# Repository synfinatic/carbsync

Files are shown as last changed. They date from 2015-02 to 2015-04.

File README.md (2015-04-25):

### CarbSync

While there are some good tools already on the market by companies like
[MotionPro](http://www.motionpro.com/motorcycle/partno/08-0411/) or 
[Morgan Carbtune](http://www.carbtune.com/), they tend to be complicated,
may use fluids which are toxic or spill, and require a complex calibration
sequence for best results.

CarbSync is a simple tool for syncing carberators or throttle bodies which uses
digital vacuum gauges to measure the vacuum on 2 to 4 cylinders.  By using 
solid-state vacuum gauges which require no calibration and have no fluid to leak,
CarbSync is both accurate and easy to use.

### Technical Specs
 * CarbSync has a useful vacuum measurement range of 0 to -7.25 PSI (-50 kPA)
     allowing it to be used with almost any vehicle
 * CarbSync has a LCD for displaying results
 * CarbSync supports 2, 3 or 4 cylinder engines
 * Powered by AA batteries

### Thanks
Special thanks to [Michael Miller](http://www.instructables.com/member/Makuna/)
for his [Arduino Throttle Body Synchronization Sheild](http://www.instructables.com/id/Arduino-Throttle-Body-Syncronization-Shield/?ALLSTEPS)
idea which gave me the idea for this project.

### License
CarbSync is licensed under the [GPLv3](http://www.gnu.org/licenses/gpl.html)

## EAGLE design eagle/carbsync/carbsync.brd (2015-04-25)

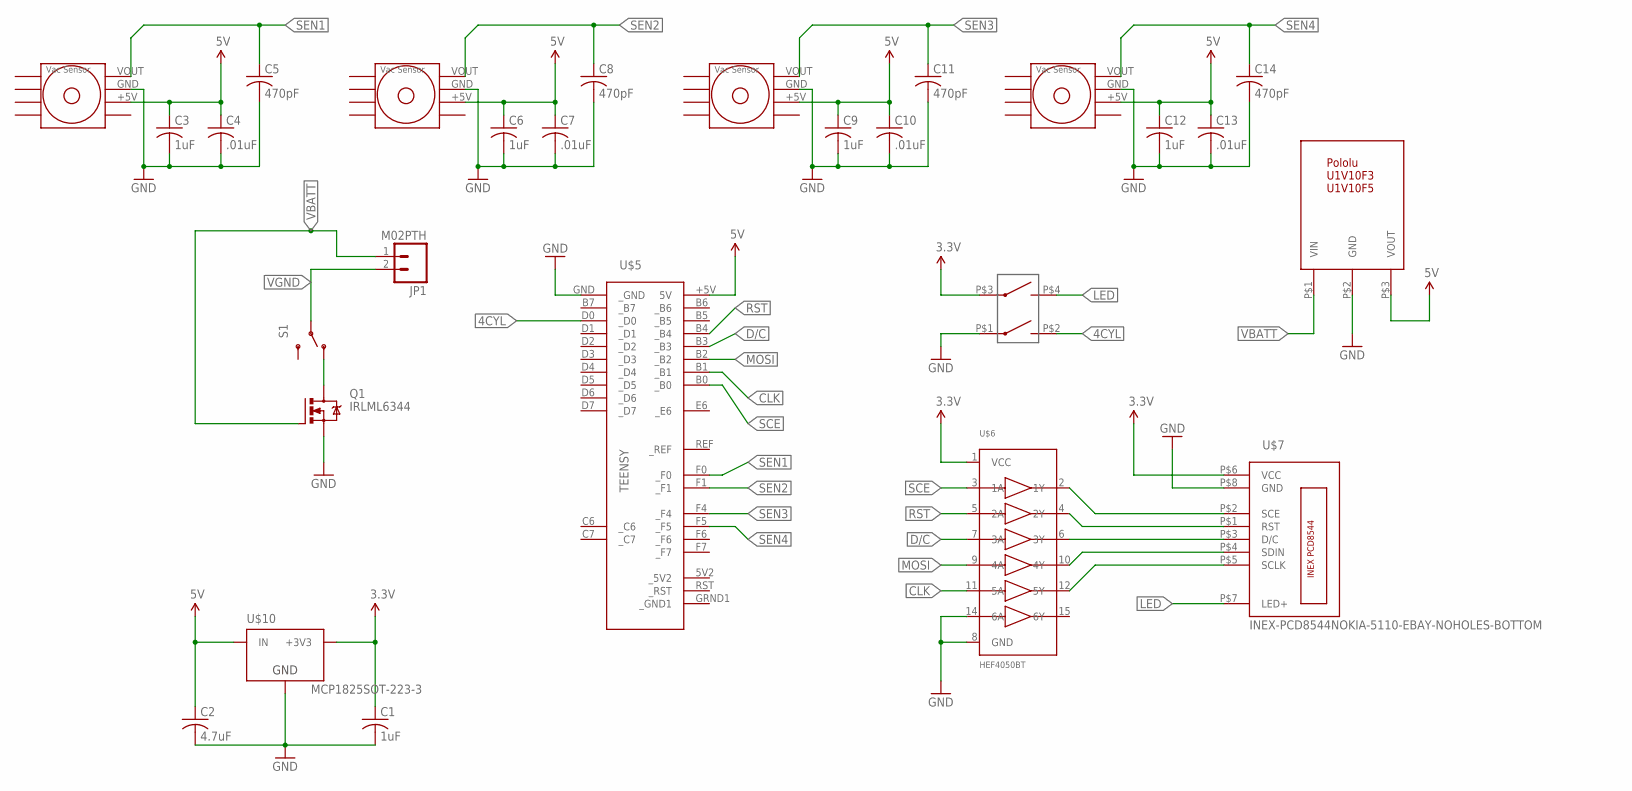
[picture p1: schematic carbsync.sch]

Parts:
C1, C3, C6, C9, C12: 1uF; C0805
C2: 4.7uF; C0805
C4, C7, C10, C13: .01uF; C0805
C5, C8, C11, C14: 470pF; C0603
JP1: M02PTH; 1X02
Q1: IRLML6344; SOT23
S1: SWITCH-SPDT; CWI286-SPDT-NOTABS
U$1, U$2, U$3, U$4: MPXV5050V
U$5: TEENSY
U$6: HEF4050BT; SOIC16
U$7: INEX-PCD8544NOKIA-5110-EBAY-NOHOLES-BOTTOM; NOKIA-5110-EBAY-NOHOLES
U$8: POLOLU-DC-3PINU1V10F5-5V-DC-UP; POLOLU-DC-3PIN
U$9: CT-219-X-MST; CT219-2-MST
U$10: MCP1825SOT-223-3; SOT-223

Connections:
3.3V: C1.1, U$6.1 (VCC), U$7.P$6 (VCC), U$9.P$3, U$10.3 (+3V3)
4CYL: U$5.D0 (_D0), U$9.P$2
5V: C2.1, C3.1, C4.1, C6.1, C7.1, C9.1, C10.1, C12.1, C13.1, U$1.+5V (5V), U$2.+5V (5V), U$3.+5V (5V), U$4.+5V (5V), U$5.+5V (5V), U$8.P$3 (VOUT), U$10.1 (IN)
CLK: U$5.B1 (_B1), U$6.11 (5A)
D/C: U$5.B3 (_B3), U$6.7 (3A)
GND: C1.2, C2.2, C3.2, C4.2, C5.2, C6.2, C7.2, C8.2, C9.2, C10.2, C11.2, C12.2, C13.2, C14.2, Q1.2 (S), U$1.GND, U$2.GND, U$3.GND, U$4.GND, U$5.GND (_GND), U$6.8 (GND), U$6.14 (6A), U$7.P$8 (GND), U$8.P$2 (GND), U$9.P$1, U$10.2 (GND), U$10.4 (GND)
LED: U$7.P$7 (LED+), U$9.P$4
MOSI: U$5.B2 (_B2), U$6.9 (4A)
unnamed: U$6.2 (1Y), U$7.P$2 (SCE)
unnamed: U$6.4 (2Y), U$7.P$1 (RST)
unnamed: U$6.6 (3Y), U$7.P$3 (D/C)
unnamed: U$6.10 (4Y), U$7.P$4 (SDIN)
unnamed: U$6.12 (5Y), U$7.P$5 (SCLK)
unnamed: Q1.3 (D), S1.P$1 (O)
RST: U$5.B4 (_B4), U$6.5 (2A)
SCE: U$5.B0 (_B0), U$6.3 (1A)
SEN1: C5.1, U$1.VOUT, U$5.F0 (_F0)
SEN2: C8.1, U$2.VOUT, U$5.F1 (_F1)
SEN3: C11.1, U$3.VOUT, U$5.F4 (_F4)
SEN4: C14.1, U$4.VOUT, U$5.F5 (_F5)
VBATT: JP1.1, Q1.1 (G), U$8.P$1 (VIN)
VGND: JP1.2, S1.P$2

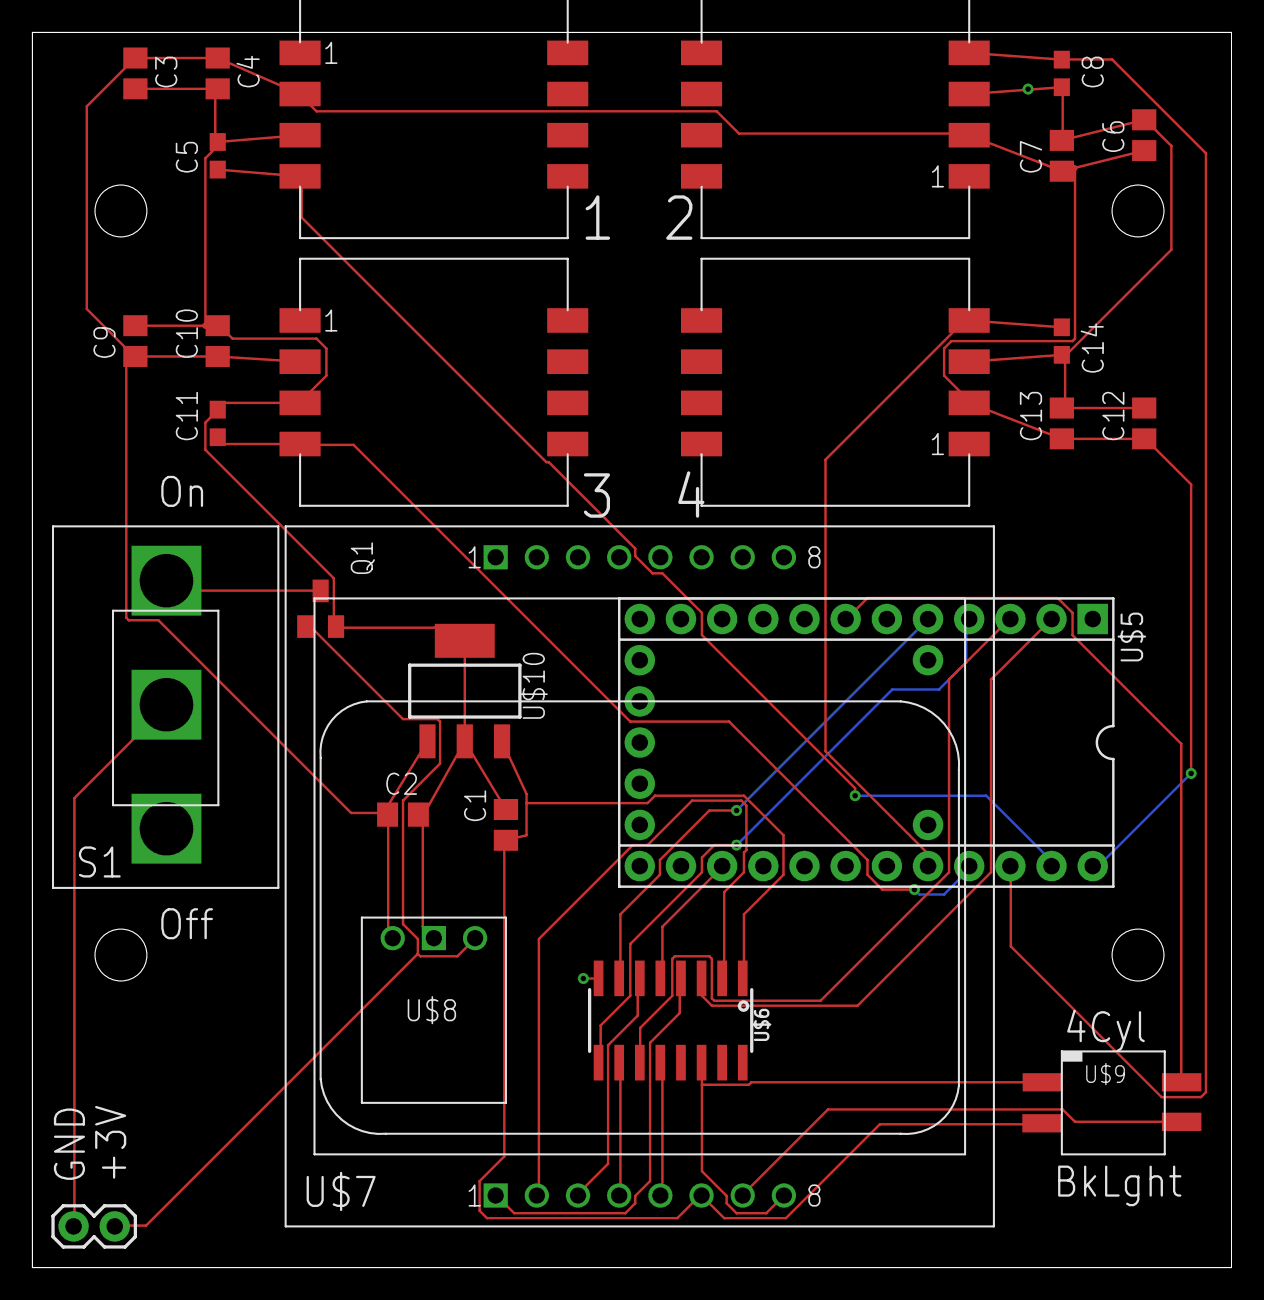
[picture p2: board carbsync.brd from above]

Board: 2 copper layers, 74.0 x 76.2 mm, 27 parts (0 on the bottom side), 22 nets.

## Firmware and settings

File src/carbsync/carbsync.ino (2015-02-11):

/* 
 * Copyright 2015 (c) Aaron Turner
 * This code is released under the GPLv3 license.  Please see the LICENSE file 
 * for details.
 *
 * More information is available here: https://github.com/synfinatic/carbsync
 */

#include <Arduino.h>
#include <Flash.h>
#include <MsTimer2.h>

#include "carbsync.h"
#include "PCD8544.h"


static PCD8544 lcd;
const int sensors[] = { SENSOR_PIN1, SENSOR_PIN2, SENSOR_PIN3, SENSOR_PIN4 };

void
setup() {
    int i;
    Serial.begin(SERIAL_SPEED);
    lcd.begin_custpins(84, 48, SCLK, SDIN, DC, RESET, SCE);

    for (i = 0; i < MAX_SENSORS ; i++) {
        pinMode(sensors[i], INPUT);
    }

    // init display
    // calibrate sensors
}

void
loop() {
    static int sensor = -1;

    sensor < MAX_SENSORS ? sensor ++ : 0;

    // 1. adc_read sensors[sensor]
    // 2. update display()
}

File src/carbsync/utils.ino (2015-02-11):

/* 
 * Copyright 2015 (c) Aaron Turner
 * This code is released under the GPLv3 license.  Please see the LICENSE file 
 * for details.
 *
 * More information is available here: https://github.com/synfinatic/carbsync
 */

#include "utils.h"

/*
 * printf to the HW serial port, useful for debugging.  Note 128char limit!
 */
void 
serial_printf(const char *fmt, ...) {
    char tmp[128]; // resulting string limited to 128 chars
    va_list args;
    va_start(args, fmt);
    vsnprintf(tmp, 128, fmt, args);
    va_end(args);
    Serial.print(tmp);
}

/*
 * printf to HW serial port, if we have debugging enabled
 */
void
dbg_serial_printf(const char *fmt, ...) {
#ifdef DEBUG
    char tmp[128]; // resulting string limited to 128 chars
    va_list args;
    va_start(args, fmt);
    vsnprintf(tmp, 128, fmt, args);
    va_end(args);
    Serial.print(tmp);
#else
    return;
#endif
}

/*
 * Float to ascii
 * Since the sprintf() of the Arduino doesn't support floating point
 * converstion, #include <stdlib.h> for itoa() and then use this function
 * to do the conversion manually
 */
char 
*ftoa(char *a, double f, int precision)
{
    long p[] = { 0,10,100,1000,10000,100000,1000000,10000000,100000000 };

    char *ret = a;
    long heiltal = (long)f;
    itoa(heiltal, a, 10);
    while (*a != '\0') a++;
    *a++ = '.';
    long desimal = abs((long)((f - heiltal) * p[precision]));
    itoa(desimal, a, 10);
    return ret;
}

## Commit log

2015-03-22 first pass at designing a board. Untested/verified
    [carbsync.brd, carbsync.sch]
2015-03-24 update & shrink board a little
    Still uses a MOSFET for reverse voltage protection,
    but I'm pretty sure it won't work.
    [carbsync.brd, carbsync.sch]
2015-03-24 remove mosfet, switch to 2-DIP instead of jumpers
    [carbsync.brd, carbsync.sch]
2015-03-28 basic 3.5x2.5" board design
    [carbsync.brd, carbsync.sch]
2015-04-02 redesign PCB around http://www.hammondmfg.com/pdf/1553D_BAT.pdf
    still need to find a power switch which will work correctly
    [carbsync.brd, carbsync.sch]
2015-04-02 clean up board and fix the level shifter
    Waiting on part order to check footprints & do power switch
    [carbsync.brd, carbsync.sch]
2015-04-25 v1.0 of PCB done and ordered
    [carbsync.brd, carbsync.sch]

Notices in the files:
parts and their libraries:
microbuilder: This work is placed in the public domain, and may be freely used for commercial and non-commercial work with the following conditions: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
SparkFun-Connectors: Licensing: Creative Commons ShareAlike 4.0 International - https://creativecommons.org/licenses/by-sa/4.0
